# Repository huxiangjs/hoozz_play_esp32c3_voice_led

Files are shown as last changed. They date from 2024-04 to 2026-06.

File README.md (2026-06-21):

# ESP32-C3 Voice LED
A low-cost LED that has both network control and voice control.

This is a sub-repository, and the main repository is located at [Hoozz Play](https://github.com/huxiangjs/hoozz_play)



## Product View
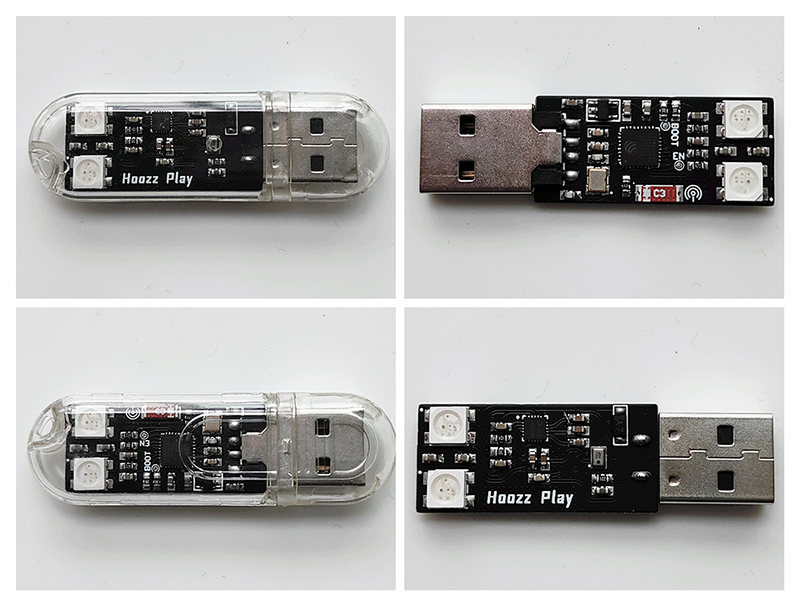
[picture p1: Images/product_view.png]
top


## Basic environment
MCU:
```
idf.py --version
ESP-IDF v5.2.1-76-gbf17be96b4-dirty
```
Circuit:
```
Altium Designer 18.1.9
```

## Default voice keywords
```c
static const char* tflite_category_labels[tflite_category_count] = {
  "silence",
  "unknown",
  "开灯",
  "关灯",
  "换颜色",
  "网络配置",
};
```

## Pull source code
```shell
git clone https://github.com/huxiangjs/hoozz_play_esp32c3_voice_led.git
cd hoozz_play_esp32c3_voice_led
git submodule update --init --recursive
```

## Compile and burn from source code
```shell
cd MCU/
idf.py build && idf.py flash
```

## You can also directly burn the released bin file

1. Download the latest release zip package from the Releases column
2. Unzip the zip and you will see the following files:
   ```
   $ tree
   .
   |-- bootloader
   |   `-- bootloader.bin
   |-- flash_args
   |-- partition_table
   |   `-- partition-table.bin
   `-- voice_led.bin

   2 directories, 4 files
   ```
3. Open the latest official download tool `flash_download_tool` (official download address: [other-tools](https://www.espressif.com/en/support/download/other-tools))
4. Use the following options: (1) `Chip Type [ESP32-C3]`; (2) `WorkMode [Develop]`; (3) `LoadMode [USB]`;
5. According to the content of the `flash_args` file, configure the burning file, address and flash type. Keep the default selection for places not mentioned, and finally click **Start** to burn

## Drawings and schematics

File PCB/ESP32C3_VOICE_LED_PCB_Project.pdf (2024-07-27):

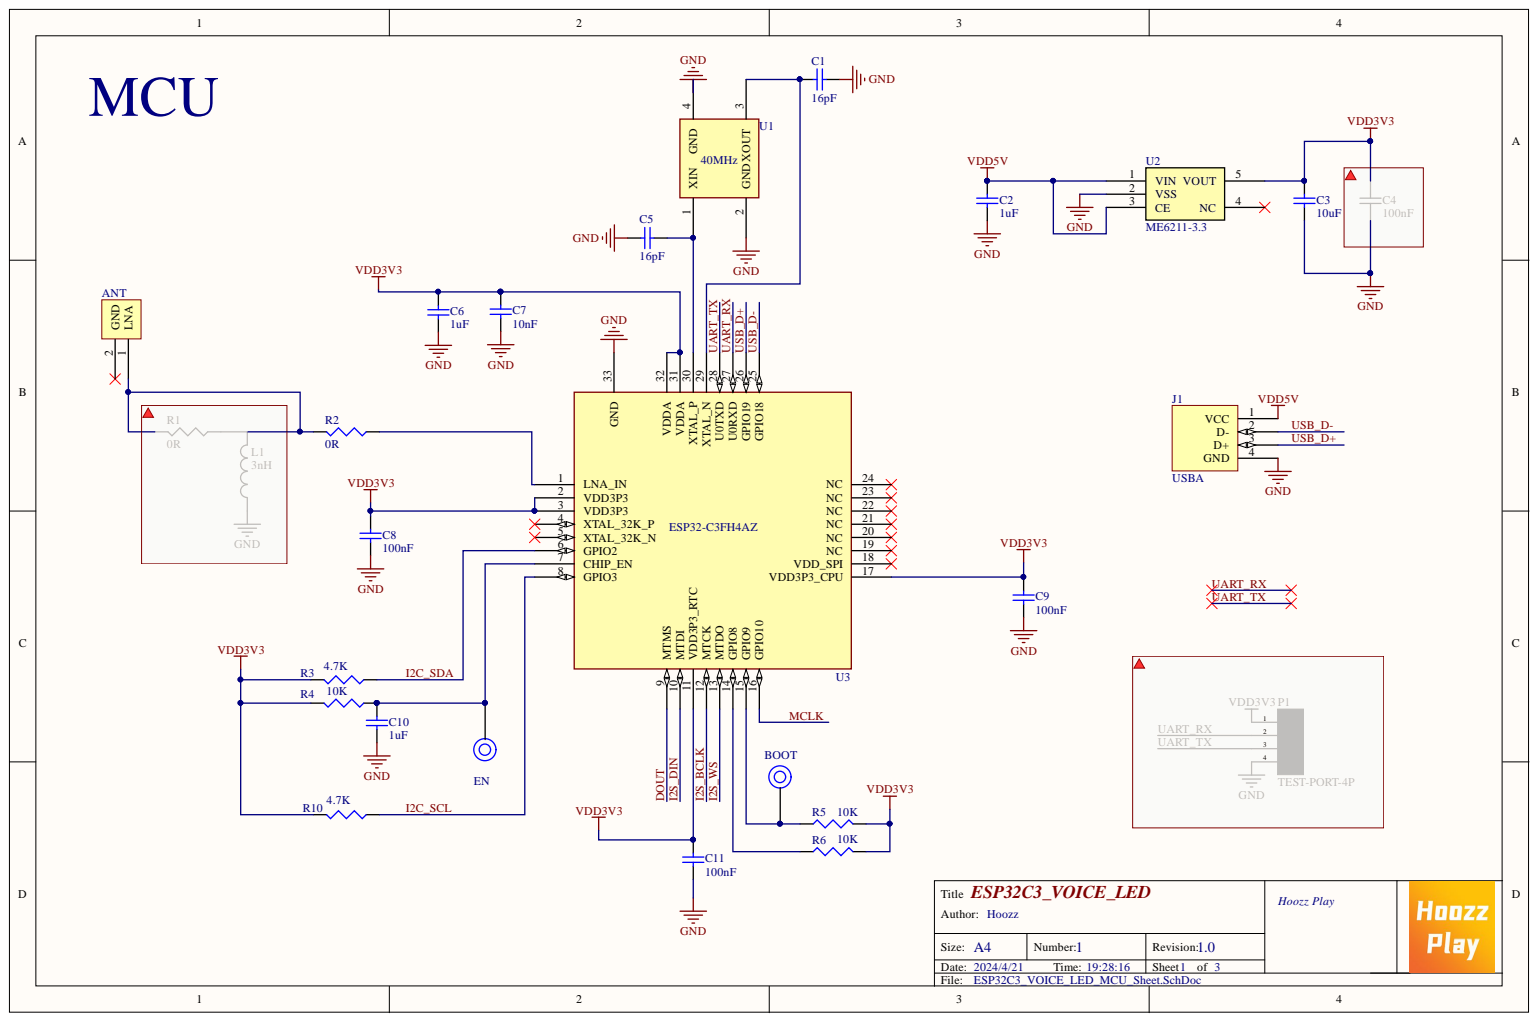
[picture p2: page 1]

G | 2 | 4 | C3

7 | 1 8
8 | 1 7

D I2C_SD A E N I2C_SCL

ESP3 2C3 _VOICE_LED 1 T i t l e A u t h or: H o ozz | H o o z z P l a y

A4 Size: | N umber: | 1.0 Rev i s i o n :
Date: / / T ime: : : | | Sheet o f

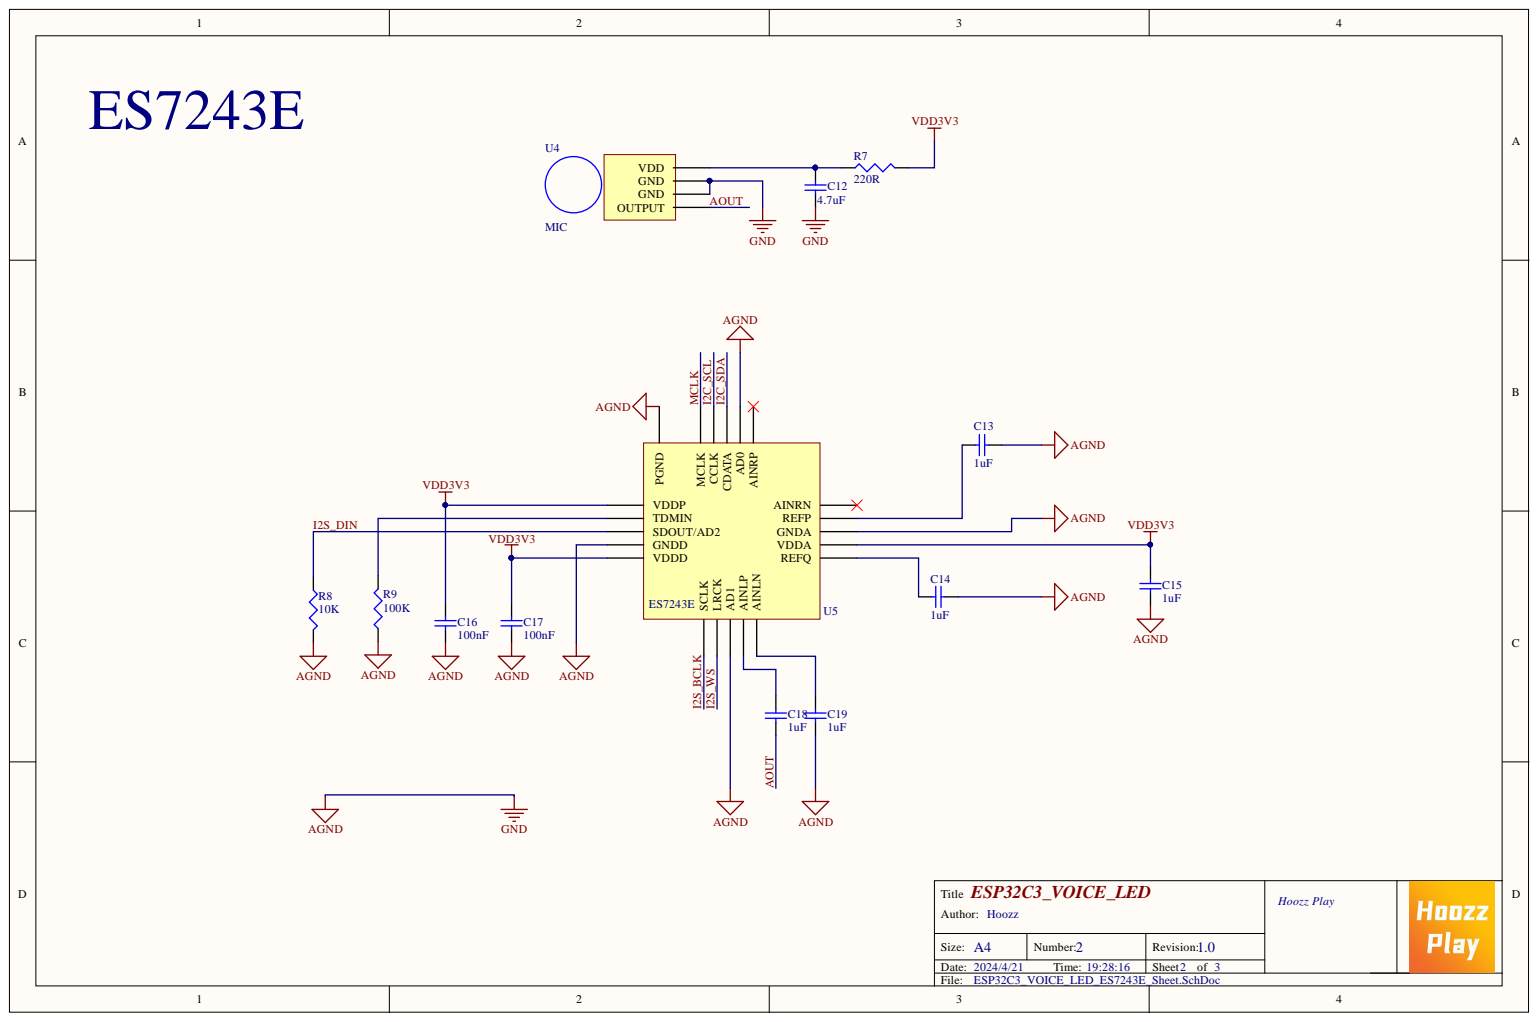
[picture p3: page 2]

ESP32C3_VOICE_LED Title Author: Hoozz | Hoozz Play

A4 Size: | 2 Number: | 1.0 Revision:
2024/4/21 Time: 19:28:16 | | Sheet of

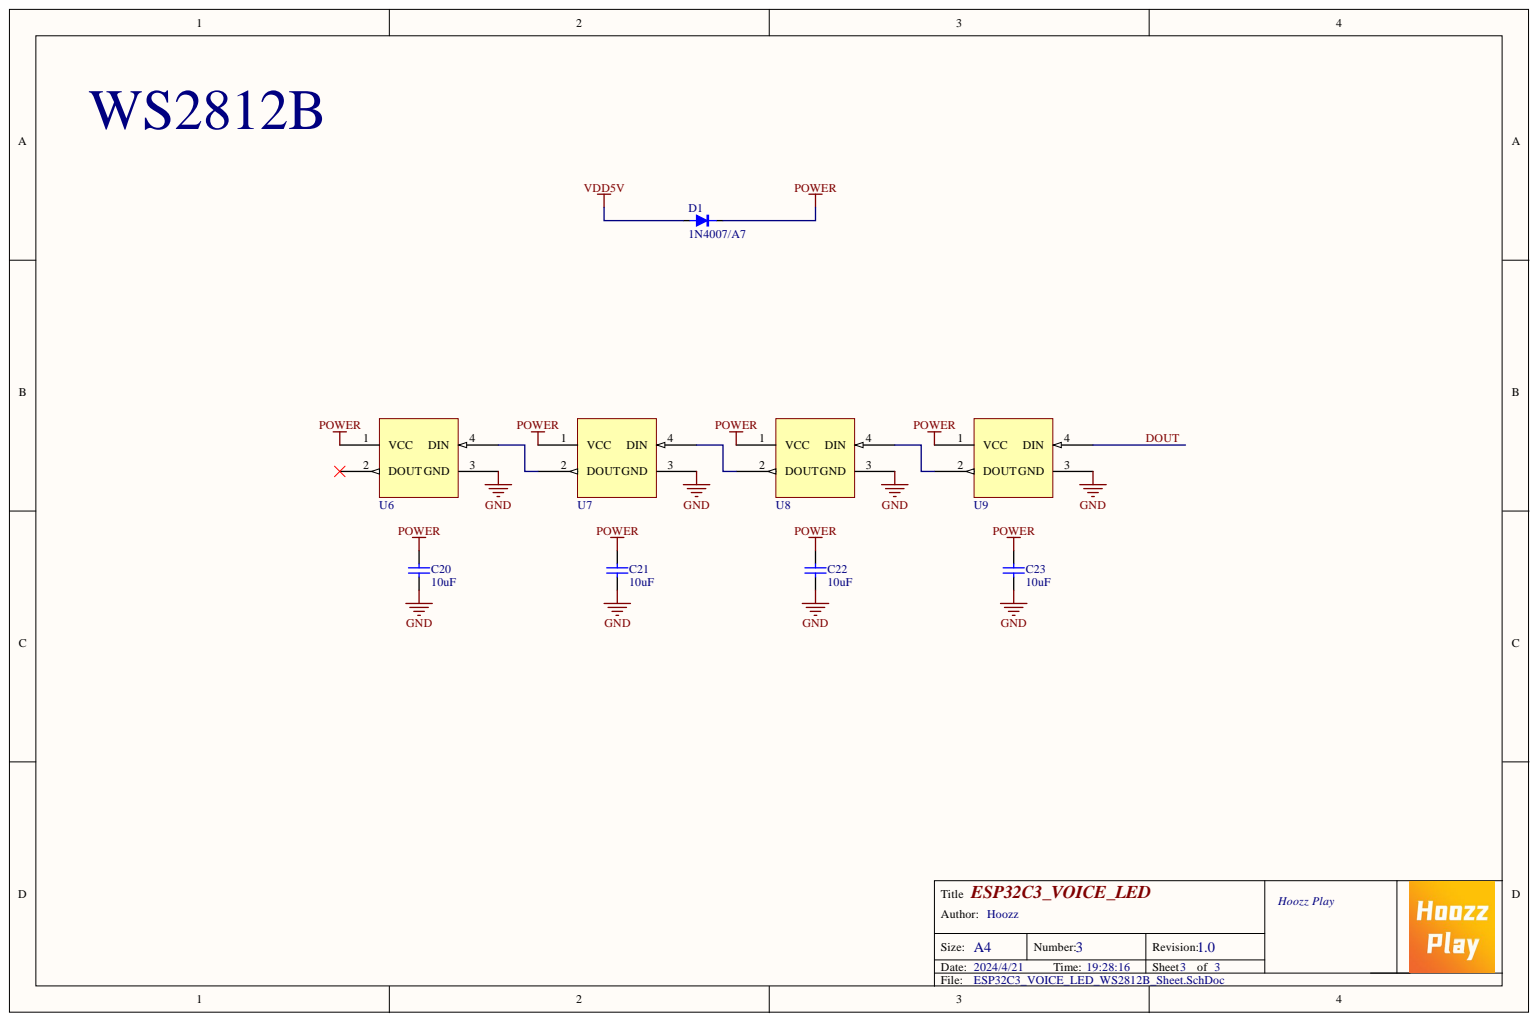
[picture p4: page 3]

ESP32C3_VOICE_LED Title Author: Hoozz | Hoozz Play

A4 Size: | 3 Number: | 1.0 Revision:
2024/4/21 Time: 19:28:16 | | Sheet of

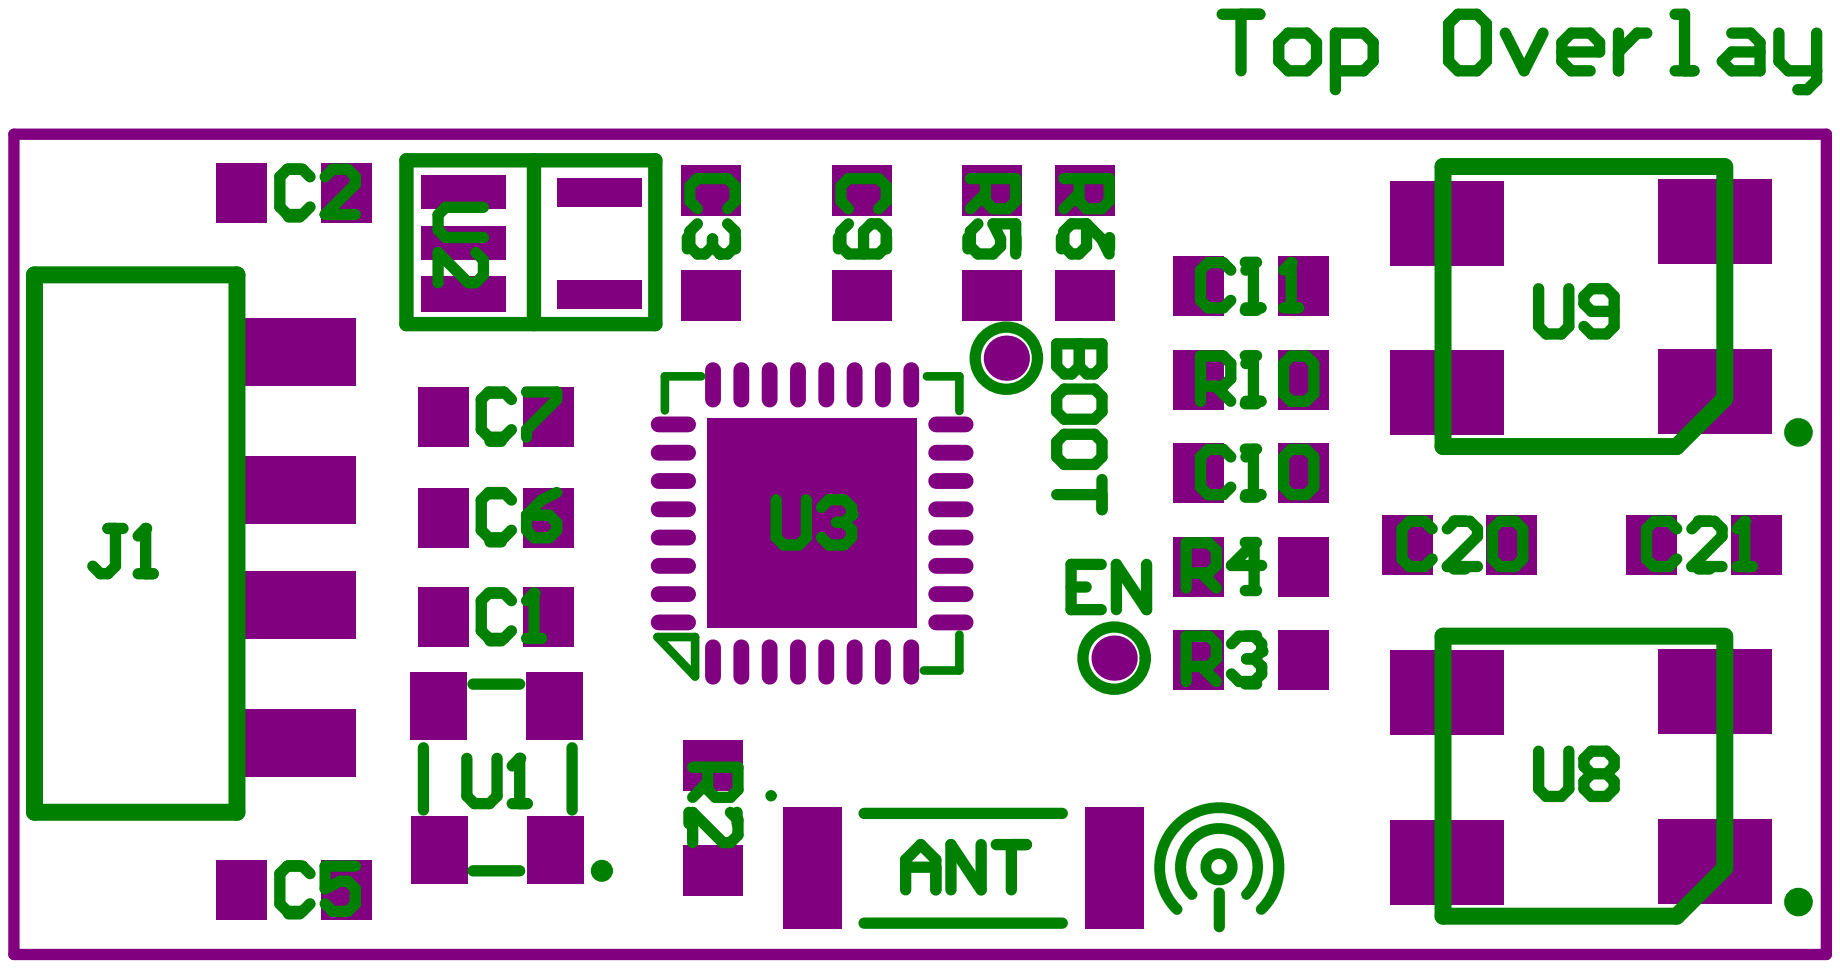
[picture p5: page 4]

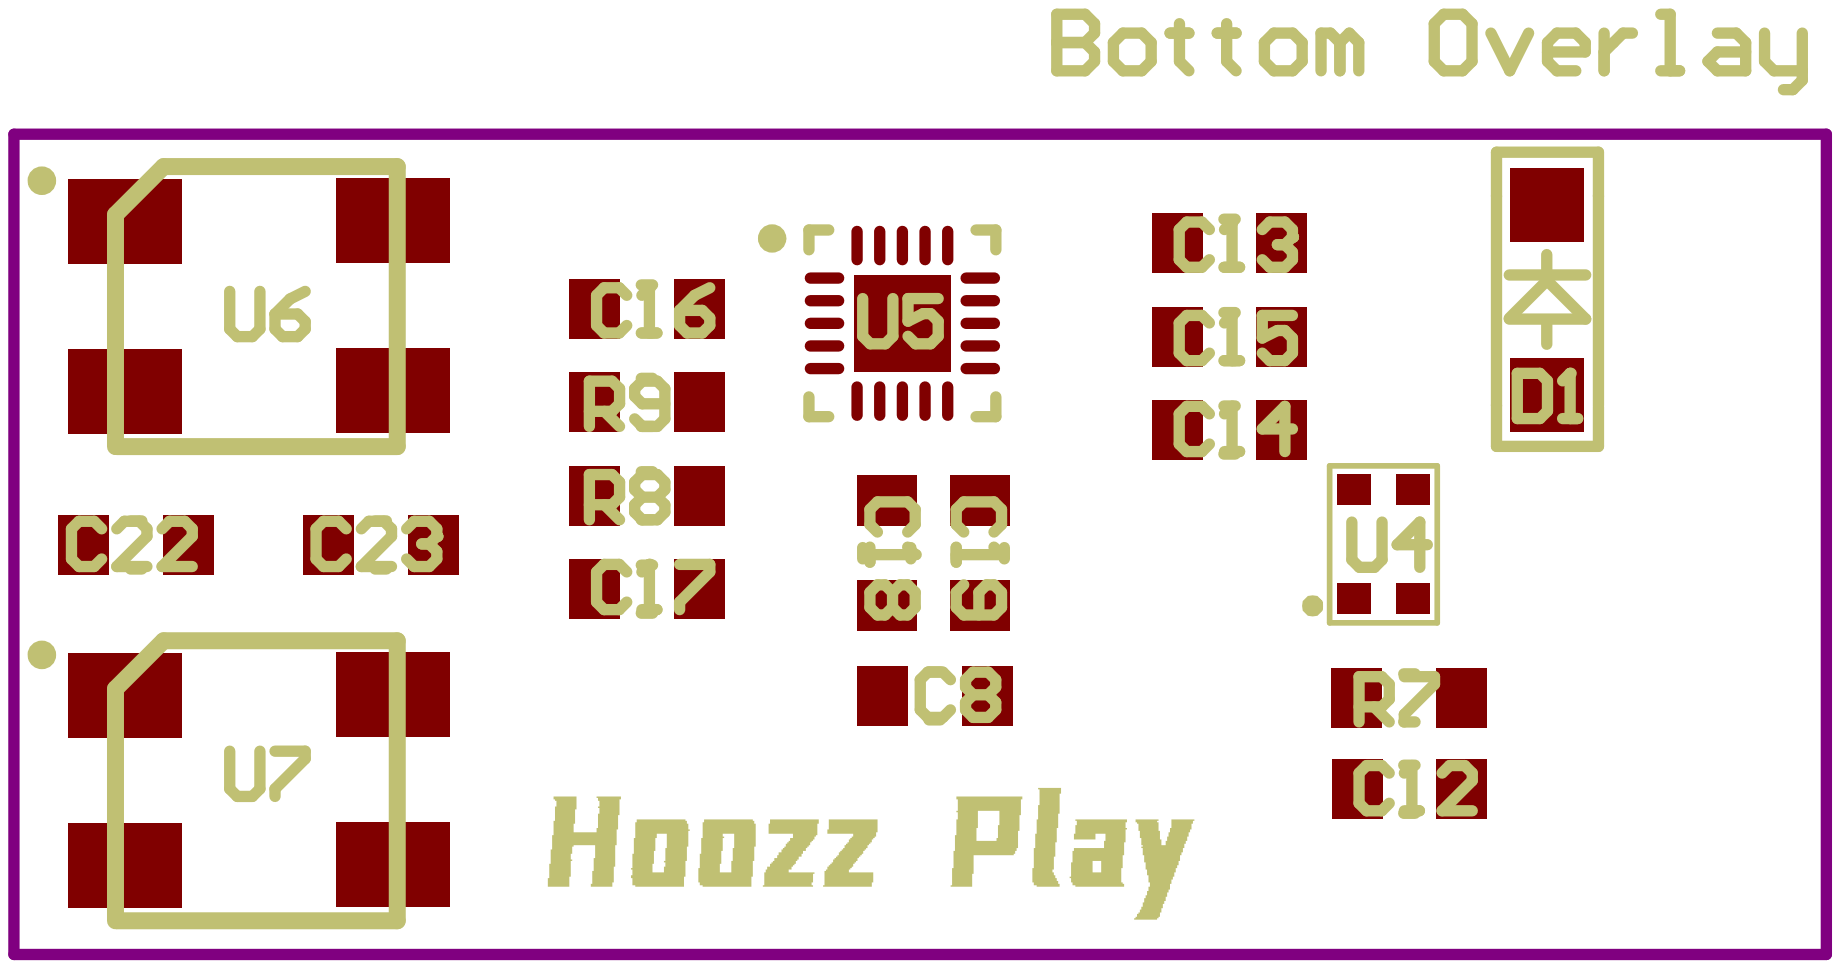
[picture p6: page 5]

Component list | Bill of Materials For Project [ESP32C3_VOICE_LED_PCB_Project.PrjPCB] (No PCB Document Selected)
Source Data From: | | ESP32C3_VOICE_LED_PCB_Project.PrjPCB
Project: | | ESP32C3_VOICE_LED_PCB_Project.PrjPCB
Variant: | | None
Report Date: | 2024/4/21 | 19:28:19
Print Date: | 21-Apr-24 | 7:28:38 PM
# | Designator | Comment | Value | Footprint | Description | Pins | LibRef | Quantity

1 | ANT | ANT | | CA-C03 | | 2 | ANT | 1
2 | BOOT, EN | TEST-PORT | | TEST-PORT | | 1 | TEST-PORT | 2
3 | C1, C5 | Cap | 16pF | 0603 | Capacitor | 2 | Cap | 2
4 | C2, C6, C10, C13, C14, C15, C18, C19 | Cap | 1uF | 0603 | Capacitor | 2 | Cap | 8
5 | C3, C20, C21, C22, C23 | Cap | 10uF | 0603 | Capacitor | 2 | Cap | 5
6 | C7 | Cap | 10nF | 0603 | Capacitor | 2 | Cap | 1
7 | C8, C9, C11, C16, C17 | Cap | 100nF | 0603 | Capacitor | 2 | Cap | 5
8 | C12 | Cap | 4.7uF | 0603 | Capacitor | 2 | Cap | 1
9 | D1 | 1N4007/A7 | | SOD-123FL | | 2 | DIODE | 1
10 | J1 | USBA | | USB-A-2 | USB2.0 | 4 | USBA | 1
11 | R2 | Res | 0R | 0603 | Resistor | 2 | Res | 1
12 | R3, R10 | Res | 4.7K | 0603 | Resistor | 2 | Res | 2
13 | R4, R5, R6, R8 | Res | 10K | 0603 | Resistor | 2 | Res | 4
14 | R7 | Res | 220R | 0603 | Resistor | 2 | Res | 1
15 | R9 | Res | 100K | 0603 | Resistor | 2 | Res | 1
16 | U1 | 40MHz | | 3225 | | 4 | XTAL2 | 1
17 | U2 | ME6211-3.3 | | SOT-23-5 | No Description Available | 5 | ME6211-3.3 | 1
18 | U3 | ESP32-C3FH4AZ | | QFN32_3.7X3.7 | | 33 | ESP32-C3FH4AZ | 1
19 | U4 | MIC | | MIC_XHXDZ_2718 | | 4 | MIC_XHXDZ_2718 | 1
20 | U5 | ES7243E | | QFN20_3X3 | | 21 | ES7243E | 1
21 | U6, U7, U8, U9 | WS2812B | | 5050 | | 4 | WS2812B | 4
Approved | | | | Notes | | | | 45

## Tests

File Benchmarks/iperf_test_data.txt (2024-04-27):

------------------------------------------------------------
Client connecting to 192.168.31.135, TCP port 5001
TCP window size:  208 KByte (default)
------------------------------------------------------------
[  3] local 192.168.31.251 port 58302 connected with 192.168.31.135 port 5001
[ ID] Interval       Transfer     Bandwidth
[  3]  0.0- 1.0 sec  2.30 MBytes  19.3 Mbits/sec
[  3]  1.0- 2.0 sec  3.06 MBytes  25.7 Mbits/sec
[  3]  2.0- 3.0 sec  3.19 MBytes  26.8 Mbits/sec
[  3]  3.0- 4.0 sec  2.99 MBytes  25.1 Mbits/sec
[  3]  4.0- 5.0 sec  3.07 MBytes  25.8 Mbits/sec
[  3]  5.0- 6.0 sec  3.30 MBytes  27.7 Mbits/sec
[  3]  6.0- 7.0 sec  2.87 MBytes  24.1 Mbits/sec
[  3]  7.0- 8.0 sec  2.84 MBytes  23.8 Mbits/sec
[  3]  8.0- 9.0 sec  3.06 MBytes  25.6 Mbits/sec
[  3]  9.0-10.0 sec  2.95 MBytes  24.7 Mbits/sec
[  3] 10.0-11.0 sec  3.21 MBytes  26.9 Mbits/sec
[  3] 11.0-12.0 sec  3.26 MBytes  27.3 Mbits/sec
[  3] 12.0-13.0 sec  3.16 MBytes  26.5 Mbits/sec
[  3] 13.0-14.0 sec  3.23 MBytes  27.1 Mbits/sec
[  3] 14.0-15.0 sec  3.17 MBytes  26.6 Mbits/sec
[  3] 15.0-16.0 sec  3.30 MBytes  27.7 Mbits/sec
[  3] 16.0-17.0 sec  2.39 MBytes  20.0 Mbits/sec
[  3] 17.0-18.0 sec  2.29 MBytes  19.2 Mbits/sec
[  3] 18.0-19.0 sec  2.16 MBytes  18.1 Mbits/sec
[  3] 19.0-20.0 sec  2.35 MBytes  19.7 Mbits/sec
[  3] 20.0-21.0 sec  3.08 MBytes  25.8 Mbits/sec
[  3] 21.0-22.0 sec  3.00 MBytes  25.2 Mbits/sec
[  3] 22.0-23.0 sec  2.41 MBytes  20.2 Mbits/sec
[  3] 23.0-24.0 sec  2.66 MBytes  22.3 Mbits/sec
[  3] 24.0-25.0 sec  3.03 MBytes  25.4 Mbits/sec
[  3] 25.0-26.0 sec  2.86 MBytes  24.0 Mbits/sec
[  3] 26.0-27.0 sec  3.21 MBytes  26.9 Mbits/sec
[  3] 27.0-28.0 sec  3.33 MBytes  27.9 Mbits/sec
[  3] 28.0-29.0 sec  3.23 MBytes  27.1 Mbits/sec
[  3] 29.0-30.0 sec  3.40 MBytes  28.5 Mbits/sec
[  3] 30.0-31.0 sec  3.23 MBytes  27.1 Mbits/sec
[  3] 31.0-32.0 sec  3.31 MBytes  27.8 Mbits/sec
[  3] 32.0-33.0 sec  3.41 MBytes  28.6 Mbits/sec
[  3] 33.0-34.0 sec  3.42 MBytes  28.7 Mbits/sec
[  3] 34.0-35.0 sec  3.32 MBytes  27.8 Mbits/sec
[  3] 35.0-36.0 sec  3.34 MBytes  28.0 Mbits/sec
[  3] 36.0-37.0 sec  3.17 MBytes  26.6 Mbits/sec
[  3] 37.0-38.0 sec  3.20 MBytes  26.9 Mbits/sec
[  3] 38.0-39.0 sec  3.25 MBytes  27.3 Mbits/sec
[  3] 39.0-40.0 sec  3.13 MBytes  26.3 Mbits/sec
[  3] 40.0-41.0 sec  3.27 MBytes  27.5 Mbits/sec
[  3] 41.0-42.0 sec  3.24 MBytes  27.1 Mbits/sec
[  3] 42.0-43.0 sec  3.31 MBytes  27.7 Mbits/sec
[  3] 43.0-44.0 sec  3.04 MBytes  25.5 Mbits/sec
[  3] 44.0-45.0 sec  3.11 MBytes  26.1 Mbits/sec
[  3] 45.0-46.0 sec  2.98 MBytes  25.0 Mbits/sec
[  3] 46.0-47.0 sec  3.16 MBytes  26.5 Mbits/sec
[  3] 47.0-48.0 sec  3.17 MBytes  26.6 Mbits/sec
[  3] 48.0-49.0 sec  3.08 MBytes  25.8 Mbits/sec
[  3] 49.0-50.0 sec  3.20 MBytes  26.8 Mbits/sec
[  3] 50.0-51.0 sec  3.17 MBytes  26.6 Mbits/sec
[  3] 51.0-52.0 sec  3.10 MBytes  26.0 Mbits/sec
[  3] 52.0-53.0 sec  3.43 MBytes  28.8 Mbits/sec
[  3] 53.0-54.0 sec  3.49 MBytes  29.3 Mbits/sec
[  3] 54.0-55.0 sec  3.35 MBytes  28.1 Mbits/sec
[  3] 55.0-56.0 sec  3.26 MBytes  27.3 Mbits/sec
[  3] 56.0-57.0 sec  3.13 MBytes  26.2 Mbits/sec
[  3] 57.0-58.0 sec  3.11 MBytes  26.1 Mbits/sec
[  3] 58.0-59.0 sec  2.88 MBytes  24.2 Mbits/sec
[  3] 59.0-60.0 sec  2.61 MBytes  21.9 Mbits/sec
[  3]  0.0-60.0 sec   184 MBytes  25.8 Mbits/sec

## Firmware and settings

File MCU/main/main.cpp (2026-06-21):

/*
 * MIT License
 *
 * Copyright (c) 2024 huxiangjs
 *
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
 * THE SOFTWARE IS PROVIDED "AS IS", WITHOUT WARRANTY OF ANY KIND, EXPRESS OR
 * IMPLIED, INCLUDING BUT NOT LIMITED TO THE WARRANTIES OF MERCHANTABILITY,
 * FITNESS FOR A PARTICULAR PURPOSE AND NONINFRINGEMENT. IN NO EVENT SHALL THE
 * AUTHORS OR COPYRIGHT HOLDERS BE LIABLE FOR ANY CLAIM, DAMAGES OR OTHER
 * LIABILITY, WHETHER IN AN ACTION OF CONTRACT, TORT OR OTHERWISE, ARISING FROM,
 * OUT OF OR IN CONNECTION WITH THE SOFTWARE OR THE USE OR OTHER DEALINGS IN THE
 * SOFTWARE.
 */

#include <stdio.h>
#include <string.h>
#include <sys/unistd.h>
#include <sys/stat.h>
#include "esp_err.h"
#include "esp_log.h"
#include "esp_system.h"
#include "freertos/FreeRTOS.h"
#include "freertos/task.h"
#include "nvs_flash.h"

#include "audio.h"
#include "ws2812b.h"
#include "led_effects.h"
#include "wifi.h"
#include "event_bus.h"
#include "recognition.h"
#include "simple_ctrl.h"
#include "store.h"

static const char *TAG = "APP-MAIN";

static TaskHandle_t main_handle;
static uint32_t last_color;

#define LED_CMD_SET_COLOR		0x00
#define LED_CMD_GET_COLOR		0x01

#define LED_RESULT_OK			0x00
#define LED_RESULT_FAIL			0x01

#define CASE_BIT(X)			(1 << (X))
#define CASE_1_TURN_ON			CASE_BIT(0)
#define CASE_2_TURN_OFF			CASE_BIT(1)
#define CASE_3_SWITCH			CASE_BIT(2)
#define CASE_4_CONFIG			CASE_BIT(3)

static uint32_t case_bitmap;

static void app_show_info(void)
{
	int size = esp_get_free_heap_size();

	ESP_LOGI(TAG, "Free heap size: %dbytes", size);
}

static int app_led_request(char *buffer, int buf_offs, int vaild_size, int buff_size)
{
	uint32_t rgb = 0;

	if (vaild_size < 1) {
		ESP_LOGE(TAG, "Information command is incorrect");
		return -1;
	}

	if (buff_size - buf_offs < 5) {
		ESP_LOGE(TAG, "Not enough buffer space");
		return -1;
	}

	if (buffer[buf_offs] == LED_CMD_SET_COLOR && vaild_size == 4) {
		/* Set color */
		rgb |= buffer[buf_offs + 1] << 0;
		rgb |= buffer[buf_offs + 2] << 8;
		rgb |= buffer[buf_offs + 3] << 16;
		// led_effects_play(LED_EFFECTS_COLOR_FILL, rgb);
		led_effects_play(LED_EFFECTS_COLOR_GRADIENT, rgb);
		ESP_LOGI(TAG, "Set color: #%06x", (unsigned int)rgb);
		/* Set return (2byte) */
		buffer[buf_offs + 1] = LED_RESULT_OK;
		if (rgb)
			case_bitmap = CASE_2_TURN_OFF | CASE_3_SWITCH;
		else
			case_bitmap = CASE_1_TURN_ON;
		return 2;
	} else if (buffer[buf_offs] == LED_CMD_GET_COLOR && vaild_size == 1) {
		ESP_LOGI(TAG, "Get color: #%06x", (unsigned int)last_color);
		/* Set return (5byte) */
		buffer[buf_offs + 1] = LED_RESULT_OK;
		buffer[buf_offs + 2] = (uint8_t)((last_color >> 0) & 0xff);
		buffer[buf_offs + 3] = (uint8_t)((last_color >> 8) & 0xff);
		buffer[buf_offs + 4] = (uint8_t)((last_color >> 16) & 0xff);
		return 5;
	} else {
		ESP_LOGE(TAG, "Lllegal command");
		return -1;
	}

	return 0;
}

static uint8_t pick_index;

static uint32_t app_get_color(bool next)
{
	static const uint32_t colors[] = {
		0xffffff, 0xff4e00, 0xff1123,
		0xec05ff, 0x00d3ff, 0x00ff2e,
		0xff3588, 0xb981ff, 0x67ffa3,
	};

	uint32_t color;

	if (next)
		pick_index++;
	color = colors[pick_index];
	ESP_LOGD(TAG, "[%d]: %06X", (int)pick_index, (int)color);

	pick_index %= sizeof(colors) / sizeof(colors[0]);

	return color;
}

static void app_led_notify(uint32_t color)
{
	char rgb[3];

	last_color = color;

	rgb[0] = (uint8_t)((color >> 0) & 0xff);
	rgb[1] = (uint8_t)((color >> 8) & 0xff);
	rgb[2] = (uint8_t)((color >> 16) & 0xff);

	simple_ctrl_notify(rgb, sizeof(rgb));
}

static uint8_t recognition_threshold[] = {60, 50, 60, 60};

static bool app_event_notify_callback(struct event_bus_msg *msg)
{
	switch (msg->type) {
	case EVENT_BUS_STARTUP:
		break;
	case EVENT_BUS_START_SMART_CONFIG:
		break;
	case EVENT_BUS_STOP_SMART_CONFIG:
		case_bitmap = CASE_1_TURN_ON;
		break;
	case EVENT_BUS_AUDIO_RECOGNITION:
		/* Use threshold control to reduce false recognition rate */
		if ((msg->param1 < (sizeof(recognition_threshold) / sizeof(recognition_threshold[0]))) &&
		    (msg->param2 >= recognition_threshold[msg->param1])) {
			/* Turn on */
			if ((case_bitmap & CASE_1_TURN_ON) && (msg->param1 == 0)) {
				case_bitmap = CASE_2_TURN_OFF | CASE_3_SWITCH;
				led_effects_play(LED_EFFECTS_COLOR_FILL, app_get_color(false));
				ESP_LOGI(TAG, "Turn on");
			}
			/* Turn off */
			if ((case_bitmap & CASE_2_TURN_OFF) && (msg->param1 == 1)) {
				case_bitmap = CASE_1_TURN_ON;
				led_effects_play(LED_EFFECTS_ALL_OFF, 0);
				ESP_LOGI(TAG, "Turn off");
			}
			/* Switch color */
			if ((case_bitmap & CASE_3_SWITCH) && (msg->param1 == 2)) {
				led_effects_play(LED_EFFECTS_COLOR_FILL, app_get_color(true));
				ESP_LOGI(TAG, "Switch color");
			}
			/* Smart config */
			if ((case_bitmap & CASE_4_CONFIG) && (msg->param1 == 3)) {
				ESP_LOGI(TAG, "Smart config");
				case_bitmap = 0;
				xTaskNotifyGive(main_handle);
			}
		}
		break;
	case EVENT_BUS_LED_COLOR_UPDATED:
		ESP_LOGD(TAG, "Color updated");
		app_led_notify(msg->param1);
		break;
	}

	return false;
}

extern "C" void app_main(void)
{
	struct event_bus_msg msg = { EVENT_BUS_STARTUP, 0, 0};

	app_show_info();
	ESP_ERROR_CHECK(nvs_flash_init());

	main_handle = xTaskGetCurrentTaskHandle();

	store_init();

	/* Event bus */
	event_bus_init();
	event_bus_register(app_event_notify_callback);
	event_bus_send(&msg);

	/* LED */
	led_effects_init();

	/* Audio recognition */
	recognition_init();
	vTaskDelay(pdMS_TO_TICKS(100));

	/* Wifi */
	wifi_init();

	/* Network ctrl */
	simple_ctrl_init();
	simple_ctrl_set_name("VOICE LED");
	simple_ctrl_set_class_id(CLASS_ID_VOICE_LED);
	simple_ctrl_request_register(app_led_request);

	case_bitmap = CASE_4_CONFIG;
	ulTaskNotifyTake(pdTRUE, pdMS_TO_TICKS(8000));
	if (case_bitmap & CASE_4_CONFIG) {
		case_bitmap = CASE_1_TURN_ON;
		wifi_connect();
	} else {
		wifi_smartconfig();
	}

	app_show_info();
}

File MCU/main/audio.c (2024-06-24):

/*
 * MIT License
 *
 * Copyright (c) 2024 huxiangjs
 *
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
 * THE SOFTWARE IS PROVIDED "AS IS", WITHOUT WARRANTY OF ANY KIND, EXPRESS OR
 * IMPLIED, INCLUDING BUT NOT LIMITED TO THE WARRANTIES OF MERCHANTABILITY,
 * FITNESS FOR A PARTICULAR PURPOSE AND NONINFRINGEMENT. IN NO EVENT SHALL THE
 * AUTHORS OR COPYRIGHT HOLDERS BE LIABLE FOR ANY CLAIM, DAMAGES OR OTHER
 * LIABILITY, WHETHER IN AN ACTION OF CONTRACT, TORT OR OTHERWISE, ARISING FROM,
 * OUT OF OR IN CONNECTION WITH THE SOFTWARE OR THE USE OR OTHER DEALINGS IN THE
 * SOFTWARE.
 */

#include <string.h>
#include <stdio.h>
#include <stdint.h>
#include <stdbool.h>

#include "sdkconfig.h"
#include "esp_log.h"
#include "freertos/FreeRTOS.h"
#include "freertos/task.h"
#include "argtable3/argtable3.h"
#include "driver/i2c.h"
#include "driver/i2s_tdm.h"

#include <fvad.h>
#include <es7243e.h>

#include "audio.h"
#include "sample_send.h"

// #define DEBUG

#define ES7243E_ADDR			0x10		// AD0 AD1 AD2 is low

#define AUDIO_SAMPLE_DEPTH		(16 / 8)	// 16-bit: 2-byte
#define AUDIO_SAMPLE_RATE		16000		// 16kHz

#define AUDIO_MIN_TIME			300		// 400ms
#define AUDIO_FILTER_TIME		100		// 100ms

// Sampled and sent to Serial or TCP
// #define ENABLE_SAMPLE_SEND

static const char *TAG = "AUDIO";

static i2s_chan_handle_t rx_chan;
static struct audio_handler audio_hand;

static uint16_t audio_frame_time;
static uint16_t audio_sample_point;
static uint16_t audio_frame_size;
static uint8_t *audio_frame_buf;

static uint16_t audio_max_time;
static uint16_t audio_time_count;

static void audio_i2c_init(void)
{
	i2c_config_t conf = {
		.mode = I2C_MODE_MASTER,
		.sda_io_num = GPIO_NUM_2,
		.sda_pullup_en = GPIO_PULLUP_ENABLE,
		.scl_io_num = GPIO_NUM_3,
		.scl_pullup_en = GPIO_PULLUP_ENABLE,
		.master.clk_speed = 100000,
	};

	i2c_driver_install(I2C_NUM_0, I2C_MODE_MASTER, 0, 0, 0);
	ESP_ERROR_CHECK(i2c_param_config(I2C_NUM_0, &conf));
}

static void audio_i2c_scan(void)
{
	uint8_t address;
	char buffer[512];
	uint16_t index = 0;

	index += snprintf(buffer + index, sizeof(buffer) - index,
			  "\r\n     0  1  2  3  4  5  6  7  8  9  a  b  c  d  e  f\r\n");
	for (int i = 0; i < 128; i += 16) {
		index += snprintf(buffer + index, sizeof(buffer) - index,"%02x: ", i);
		for (int j = 0; j < 16; j++) {
			address = i + j;
			i2c_cmd_handle_t cmd = i2c_cmd_link_create();
			i2c_master_start(cmd);
			i2c_master_write_byte(cmd, (address << 1) | I2C_MASTER_WRITE, true);
			i2c_master_stop(cmd);
			esp_err_t ret = i2c_master_cmd_begin(I2C_NUM_0, cmd, 50 / portTICK_PERIOD_MS);
			i2c_cmd_link_delete(cmd);
			if (ret == ESP_OK) {
				index += snprintf(buffer + index, sizeof(buffer) - index, "%02x ", address);
			} else if (ret == ESP_ERR_TIMEOUT) {
				index += snprintf(buffer + index, sizeof(buffer) - index, "UU ");
			} else {
				index += snprintf(buffer + index, sizeof(buffer) - index, "-- ");
			}
		}
		index += snprintf(buffer + index, sizeof(buffer) - index, "\r\n");
	}

	ESP_LOGI(TAG, "%s", buffer);
}

static void audio_i2s_init(void)
{
	i2s_chan_config_t rx_chan_cfg = I2S_CHANNEL_DEFAULT_CONFIG(I2S_NUM_AUTO, I2S_ROLE_MASTER);
	ESP_ERROR_CHECK(i2s_new_channel(&rx_chan_cfg, NULL, &rx_chan));

	i2s_tdm_config_t rx_tdm_cfg = {
		.clk_cfg  = I2S_TDM_CLK_DEFAULT_CONFIG(AUDIO_SAMPLE_RATE),
		.slot_cfg = I2S_TDM_MSB_SLOT_DEFAULT_CONFIG(I2S_DATA_BIT_WIDTH_16BIT,
							    I2S_SLOT_MODE_MONO,
							    I2S_TDM_SLOT0),
		.gpio_cfg = {
			.mclk = GPIO_NUM_10,
			.bclk = GPIO_NUM_6,
			.ws   = GPIO_NUM_7,
			.dout = I2S_GPIO_UNUSED,
			.din  = GPIO_NUM_5,
			.invert_flags = {
				.mclk_inv = false,
				.bclk_inv = false,
				.ws_inv   = false, // Left Channel
				// .ws_inv   = true, // Right Channel
			},
		},
	};

	rx_tdm_cfg.clk_cfg.mclk_multiple = I2S_MCLK_MULTIPLE_512;
	rx_tdm_cfg.slot_cfg.big_endian = true;

	ESP_ERROR_CHECK(i2s_channel_init_tdm_mode(rx_chan, &rx_tdm_cfg));
}

static inline void audio_send_event(uint8_t audio_event)
{
#if 0
	/*
	 * Show voice status
	 * (ESP32 needs to be followed by \r\n before outputting to the serial port)
	 */
	if (audio_event & AUDIO_EVENT_VOICE_START)
		printf("[");
	if (audio_event & AUDIO_EVENT_VOICE_FRAME)
		printf("=");
	if (audio_event & AUDIO_EVENT_VOICE_STOP)
		printf("]");
	if (audio_event & AUDIO_EVENT_VOICE_OVER)
		printf(" OVER");
	if (audio_event & AUDIO_EVENT_VOICE_DROP)
		printf(" DROP");
	if (audio_event & AUDIO_EVENT_VOICE_STOP)
		printf(" %dms\r\n", audio_time_count);
#endif

#if defined(ENABLE_SAMPLE_SEND)
	sample_send_event(audio_event, audio_frame_buf, audio_frame_size);
#else
	/* Process */
	audio_hand.event(audio_event, audio_frame_buf, audio_frame_size);
#endif
}

static void audio_i2s_read_task(void *args)
{
	size_t r_bytes = 0;
	uint16_t keep_count = 0;
	uint8_t audio_event = 0;
	uint8_t audio_vad_state = 0;
	int ret;

	Fvad *vad = fvad_new();
	ESP_ERROR_CHECK(!vad);
	ESP_ERROR_CHECK(fvad_set_sample_rate(vad, AUDIO_SAMPLE_RATE) < 0);
	ESP_ERROR_CHECK(fvad_set_mode(vad, 0) < 0);

	/* Enable the RX channel */
	ESP_ERROR_CHECK(i2s_channel_enable(rx_chan));

	while (1) {
		/* Read i2s data */
		if (i2s_channel_read(rx_chan, audio_frame_buf, audio_frame_size, &r_bytes, 1000/*ms*/) == ESP_OK) {
#if 0
			ESP_LOGI(TAG, "Read Task: i2s read %d bytes, first data: %d", r_bytes, *((short int *)audio_frame_size));
#endif
			if (audio_frame_size != r_bytes) {
				ESP_LOGE(TAG, "%d bytes of data were expected, but only %d bytes were received",
					 audio_frame_size, r_bytes);
				continue;
			}

			/* Do VAD */
			ret = fvad_process(vad, (int16_t *)audio_frame_buf, audio_sample_point);
			if (ret < 0) {
				ESP_LOGE(TAG, "VAD processing failed");
				continue;
			}
			ret = !!ret;
#if defined(DEBUG)
			printf("%c\n", ret ? '#' : '-');
#endif

			/*
			 * If the last speech was too long, wait until the speech
			 * is inactive before starting again.
			 */
			if (audio_event & AUDIO_EVENT_VOICE_OVER) {
				if (ret)
					continue;
				else
					audio_event = 0;
			}

			/* Changed */
			if (audio_vad_state ^ ret) {
				if (ret) {
					audio_time_count = audio_frame_time;
					audio_vad_state = ret;
					audio_event = AUDIO_EVENT_VOICE_START | AUDIO_EVENT_VOICE_FRAME;
					audio_send_event(audio_event);
				} else if (keep_count >= AUDIO_FILTER_TIME) {
					audio_time_count += audio_frame_time;
					audio_vad_state = ret;
					audio_event = AUDIO_EVENT_VOICE_FRAME | AUDIO_EVENT_VOICE_STOP;
					if (audio_time_count < AUDIO_MIN_TIME)
						audio_event |= AUDIO_EVENT_VOICE_DROP;
					audio_send_event(audio_event);
				}
			} else {
				/* Single frame */
				if (audio_vad_state) {
					audio_time_count += audio_frame_time;
					audio_event = AUDIO_EVENT_VOICE_FRAME;
					if (audio_time_count >= audio_max_time) {
						audio_event |= AUDIO_EVENT_VOICE_STOP | AUDIO_EVENT_VOICE_OVER;
						audio_vad_state = 0;
					}
					audio_send_event(audio_event);
				}
			}

			keep_count = ret ? 0 : (keep_count + audio_frame_time);

		} else {
			ESP_LOGE(TAG, "i2s read failed");
		}
	}
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

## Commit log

2024-04-27 Add Wi-Fi function
    [partitions.csv]
2024-04-28 Optimize LED functional control
2024-04-29 Fixed the issue of LED status being incorrect in smart config
    [led_effects.c]
2024-05-01 Add data processing framework
2024-05-06 Add control instructions for device names
2024-05-07 Add LED color control instructions
2024-05-26 Add LED color query function
2024-05-26 Optimize device ping
2024-05-28 Optimize the code in the network part
    1. Adjust TCP timeout to 30 seconds.
    2. Do not connect to WiFi before the smart configuration time has
    passed.
    3. Adjust the printing level of log.
2024-05-29 Fix: A stack overflow in task simple_ctrl_bod has been detected
    ***ERROR*** A stack overflow in task simple_ctrl_bod has been detected.
    Stack dump detected
    Core 0 register dump:
    MEPC : 0x403806d0 RA : 0x40387e0e SP : 0x3fc977f0 GP : 0x3fc94800
    0x403806d0: panic_abort at E:/01_EmbeddedDevelopment/Espressif/ESP32/esp-idf-v5.2/components/esp_system/panic.c:472
    0x40387e0e: __ubsan_include at E:/01_EmbeddedDevelopment/Espressif/ESP32/esp-idf-v5.2/components/esp_system/ubsan.c:31
2024-06-14 Fixed bug: The current recognition result is affected by the previous one
2024-06-23 Add the function of sending samples to the serial port
2024-06-24 Fixed the problem of excessive noise
    The reason is that the buffer was destroyed in advance
    [audio.c]
2024-06-29 Fixed the issue of voice and network being out of sync
    [main.cpp]
2024-07-27 Add PCB product files
    [ESP32C3_VOICE_LED_ES7243E_Sheet.SchDoc, ESP32C3_VOICE_LED_MCU_Sheet.SchDoc, ESP32C3_VOICE_LED_PCB.PcbDoc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]
2026-06-21 Add ESP32 CI workflow for building and releasing
2026-06-21 Update README with ESP32 CI badge
    Add CI badge for ESP32 project in README
